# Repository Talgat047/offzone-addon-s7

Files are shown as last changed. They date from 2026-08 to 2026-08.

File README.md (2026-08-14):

# S7 Badge for OFFZONE 2024

## Authors
- leitosama
- Unknown actor #2
- Unknown actor #3

## Design idea
- S7 Airplane with Siberian forest livery
- Airplane has air navigation lights like real planes

## Схема

`project/offzone-addon-s7.kicad_sch` — схема аэронавигационных огней, собранная по
референсному скриншоту из симулятора. До этого файл был пустой заготовкой: плата
содержала только контур и шелкографию, без футпринтов и цепей.

### Как это работает

```mermaid
flowchart LR
    VCC(["+3V"])
    GND(["GND"])

    VCC --> R1["R1 200k"] --> DIS(["DIS"])
    DIS --> R2["R2 100k"] --> TC(["TC"])
    TC --> C1["C1 10µF"] --> GND

    DIS -.->|dis| U1
    TC  -.->|tr, th| U1
    VCC -.->|Vcc, rst| U1
    U1["U1 LMC555"] -->|out| R3["R3 1k"] -->|база| Q1["Q1 КТ3153А9"]
    U1 --> GND

    VCC --> R4["R4 100"] --> BLINK(["BLINK"])
    BLINK -->|коллектор| Q1 --> GND

    BLINK --> D1["D1 мигает"] --> GND
    BLINK --> D2["D2 мигает"] --> GND
    BLINK --> D3["D3 мигает"] --> GND

    VCC --> R5["R5 100"] --> D4["D4 постоянно"] --> GND
    VCC --> R6["R6 100"] --> D5["D5 постоянно"] --> GND
```

Узел `BLINK` — это коллектор Q1. Пока `out` = 0, Q1 закрыт, R4 подтягивает `BLINK`
вверх и D1..D3 светятся. Когда `out` = 1, Q1 открывается и шунтирует `BLINK` на землю —
мигающие огни гаснут. D4 и D5 запитаны от +3V напрямую через R5/R6 и горят постоянно.

### Тайминги

| Параметр | Формула | Значение |
|---|---|---|
| `out` = 1 (огни погашены) | 0,693 · (R1 + R2) · C1 | 2,08 с |
| `out` = 0 (вспышка) | 0,693 · R2 · C1 | 0,69 с |
| Период | сумма | 2,77 с (≈ 0,36 Гц) |
| Скважность | — | 75 % |

Получается вспышка 0,69 с примерно каждые 2,8 с, то есть около 22 вспышек в минуту.

### Цепи

| Цепь | Выводы |
|---|---|
| `+3V0` | R1.1, R4.1, R5.1, R6.1, U1.4 (`/RESET`), U1.8 (`VCC`) |
| `GND` | C1.2, D1.1, D2.1, D3.1, D4.1, D5.1, Q1.3 (Э), U1.1 (`GND`) |
| `DIS` | R1.2, R2.1, U1.7 (`DIS`) |
| `TC` | C1.1, R2.2, U1.2 (`/TR`), U1.6 (`THR`) |
| `BLINK` | Q1.1 (К), R4.2, D1.2, D2.2, D3.2 |
| — | U1.3 (`OUT`) → R3.1 |
| — | R3.2 → Q1.2 (Б) |
| — | R5.2 → D4.2, R6.2 → D5.2 |
| — | U1.5 (`CONT`) — не подключён (no-connect) |

### BOM

| Поз. | Номинал | Корпус | LCSC | Примечание |
|---|---|---|---|---|
| U1 | LMC555M/TR | SOP-8 | C356725 | **CMOS**-таймер, см. замечание ниже |
| R1 | 200 кОм | 0603 | C25811 | задающая цепь |
| R2 | 100 кОм | 0603 | C25803 | задающая цепь |
| C1 | 10 мкФ | 0805 | C1713 | задающая цепь |
| R3 | 1 кОм | 0603 | C21190 | база Q1 |
| Q1 | КТ3153А9 | КТ-46А (SOT-23) | ChipDip | n-p-n, цоколёвка **1-К, 2-Б, 3-Э** |
| R4 | 100 Ом | 0603 | C105588 | общий токозадающий для D1..D3 |
| R5, R6 | 100 Ом | 0603 | C105588 | токозадающие для D4, D5 |
| D1..D3 | LED | 0805 | — | мигающие (строб / маяк) |
| D4, D5 | LED | 0805 | — | постоянные (БАНО) |

Конкретные светодиоды не выбраны: цвета — на ваше усмотрение. По-самолётному это
красный на левом крыле, зелёный на правом и белые стробы. В файле EasyEDA у D1..D5
подставлен корпус `LED0805`, партномер нужно назначить.

### Тот же проект для EasyEDA

`project/offzone-addon-s7-easyeda.json` — та же схема в формате EasyEDA Standard.
Открывается через **File → Open → EasyEDA**. Графика символов взята из библиотеки
LCSC и целиком встроена в файл, а партномера едут в атрибуте `BOM_Supplier Part`,
так что схему можно вести в плату.

`project/offzone-addon-s7-easyeda-sheet.json` — тот же лист без обёртки проекта
(один документ `docType: 1`). Запасной вариант, если проектный файл не открывается.

Отличия от KiCad-версии только в оформлении: цепи `+3V`, `GND`, `TC`, `DIS`, `OUT`,
`BLINK` разведены сетевыми метками, поэтому длинных перемычек вокруг корпуса U1 нет.
Список цепей совпадает с таблицей выше цепь в цепь.

> **Почему в компонентах пустые uuid.** Сначала в заголовки `LIB` были подставлены
> `uuid`/`puuid` библиотечных документов LCSC. При импорте EasyEDA пытается привязать
> эти документы к вашей учётной записи, они ей не принадлежат — и импорт падает с
> `Permissions Error`, создавая пустой лист. Поля оставлены пустыми, как в системной
> рамке листа; на геометрию и BOM это не влияет.

### Замечания к схеме со скриншота

1. **Таймер должен быть CMOS.** Биполярный NE555 требует минимум 4,5 В и от 3 В не
   заработает. Поставлен LMC555 (питание от 1,5 В); равноценны TLC555 и ICM7555.
   В симуляторе таймер идеальный, поэтому там это не проявляется.
2. **Потребление великовато для CR2032.** D4 и D5 берут по ~11 мА постоянно, а R4 при
   открытом Q1 сжигает ~29 мА вхолостую — в среднем около 46 мА. CR2032 (~220 мАч)
   такой ток не держит. Если питание автономное, стоит поднять R5/R6 до 1–2 кОм и
   перенести D1..D3 в коллекторную цепь Q1 (тогда R4 работает только во время вспышки).
3. **Вывод `ctl` оставлен свободным**, как на скриншоте. На реальной плате его обычно
   шунтируют конденсатором 10 нФ на землю.
4. **У КТ3153А9 своя цоколёвка.** По даташитам «Далекс» и ОАО «Интеграл» в корпусе
   КТ-46А (SOT-23) вывод 1 — коллектор, 2 — база, 3 — эмиттер. У западных SOT-23
   (MMBT3904, BC847) порядок другой: 1 — база, 2 — эмиттер, 3 — коллектор. Посадочное
   место нужно нумеровать по даташиту, иначе транзистор включится «наизнанку».
   По параметрам запас большой: Iк max 400 мА против рабочих ~30 мА, h21э 100…300 —
   базового тока (3 В − 0,85 В)/1 кОм ≈ 2 мА хватает для насыщения с большим запасом.

### Что осталось сделать

- Футпринты компонентам не назначены — цепи в `.kicad_pcb` ещё не разведены.
- Источник питания в схеме не нарисован: +3V приходит либо с хост-бейджа через разъём
  аддона, либо от CR2032. Разъём/держатель нужно добавить отдельно.

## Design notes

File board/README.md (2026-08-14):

# Плата-самолёт: разводка

`plane_easyeda_routed.json` — плата 65 × 65,5 мм в формате EasyEDA Standard,
собранная из расстановки в `plane_easyeda.json` и разведённая полностью.
Открывается через **File → Open → EasyEDA**.

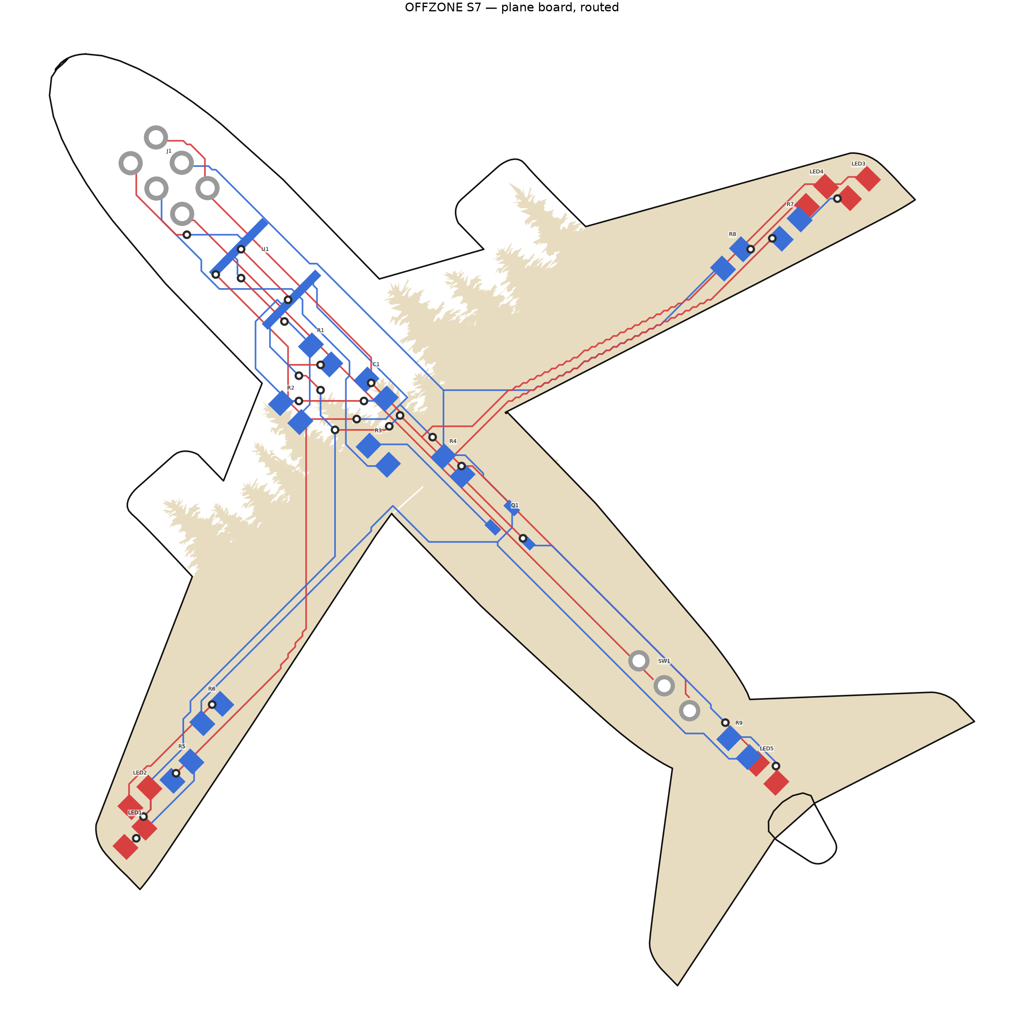
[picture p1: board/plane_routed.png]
разводка


## Что изменено относительно исходной расстановки

| Что | Было | Стало | Почему |
|---|---|---|---|
| Q1 | `KT-13-SMD`, три площадки в ряд с шагом 2,5 мм, цепи 1-GND 2-LEDDRV 3-BASE | `SOT-23`, цепи **1-LEDDRV (К), 2-BASE (Б), 3-GND (Э)** | КТ3153А9 выпускается в КТ-46А (SOT-23), и его цоколёвка — 1 коллектор, 2 база, 3 эмиттер |
| LED1, LED3 | питались от `LEDDRV` | питаются от `VCC` через R5 и R7 | по схеме со скриншота два огня горят постоянно |
| LED2 | — | сдвинут на 0,41 мм от LED1 | площадки LED1.2(GND) и LED2.1(A2) стояли в 0,068 мм |
| LED4 | — | сдвинут на 0,56 мм от LED3 | площадки LED3.1(A3) и LED4.2(GND) стояли в 0,004 мм |

Два последних пункта — исправление замыкания: в исходной расстановке пары на
законцовках стояли в 2,42 мм друг от друга, и встречные площадки корпусов 0805
соприкасались. LED2 и LED3 оказались бы закорочены на землю и не зажглись бы.
Теперь зазор 0,315 и 0,316 мм.

## Огни

| Позиция | Место | Режим |
|---|---|---|
| LED1 | законцовка левого крыла | постоянно (БАНО) |
| LED2 | законцовка левого крыла | мигает |
| LED3 | законцовка правого крыла | постоянно (БАНО) |
| LED4 | законцовка правого крыла | мигает |
| LED5 | хвост | мигает |

Разбивка «по одному постоянному на крыло, остальные мигают» повторяет
аэронавигационные огни настоящего самолёта: ровные БАНО на крыльях плюс
проблесковые маяки. Цвета светодиодов не заданы — по-самолётному это красный
на левом крыле и зелёный на правом.

## Параметры разводки

| Параметр | Значение |
|---|---|
| Слои | 2 (TopLayer — светодиоды, BottomLayer — обвязка) |
| Ширина дорожки | 0,254 мм (10 mil) |
| Зазор | 0,254 мм (10 mil) |
| Переходное отверстие | 0,61 мм, сверло 0,3 мм |
| Отступ меди от контура | 0,5 мм |
| Дорожек / переходов | 50 / 28 |
| Суммарная длина дорожек | 532 мм |

Нормы с большим запасом относительно JLCPCB (минимум 0,127 мм / 5 mil).

## Проверки

`build_board.py` пересобирает плату из исходной расстановки и сам себя проверяет:

- каждая цепь — один связный остров меди (выводные площадки J1 и SW1 считаются
  соединяющими слои, как и переходные отверстия);
- нет нарушений зазора между дорожками и чужой медью;
- нет площадок разных цепей ближе 0,3 мм;
- ни одна дорожка, переход или площадка не выходит за контур платы и не попадает
  в отверстие под шнурок (проверено по 5926 точкам).

```
python build_board.py plane_easyeda.json plane_easyeda_routed.json
python render_pcb.py  plane_easyeda_routed.json plane_routed.png
```

## Чего в плате нет

- **Держателя батарейки.** По расчёту в `layout.py` при ширине 65 мм наибольшая
  вписанная окружность — 16,5 мм, а держателю CR2032 нужно 20 мм. Питание идёт
  через J1 (`VBAT`) и выключатель SW1.
- **Полигона земли.** Земля разведена дорожками; при желании можно залить
  полигон, но на таких токах это не обязательно.
- **Проверки зеркальности посадочных мест.** Компоненты стоят на нижнем слое, а
  генератор кладёт площадки без зеркалирования. Для двухвыводных резисторов и
  конденсаторов это неважно, но у U1 (SOIC-8), J1, SW1 и Q1 порядок выводов при
  монтаже снизу зеркалится. Это надо проверить до заказа — я эту логику не
  трогал, чтобы не расходиться с вашим генератором.

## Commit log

2026-08-14 Add navigation lights schematic
    offzone-addon-s7.kicad_sch was an empty stub: the board carried only the
    outline and silkscreen, with no footprints and no nets. Fill it in with the
    circuit from the reference simulator screenshot.
    - U1 CMOS 555 astable, R1 200k / R2 100k / C1 10uF -> 0.69 s flash every
    2.77 s (~0.36 Hz, 75% duty)
    - out -> R3 1k -> Q1 NPN low-side switch
    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
    [offzone-addon-s7.kicad_sch]
2026-08-14 Add EasyEDA version of the schematic
    project/offzone-addon-s7-easyeda.json holds the same circuit as the KiCad
    sheet, in EasyEDA Standard format (File -> Open -> EasyEDA). Symbols are the
    real LCSC ones, so footprints and part numbers come along and the sheet can be
    pushed straight to a board.
    Nets +3V, GND, TC, DIS, OUT and BLINK are joined by net labels rather than long
    wires, which keeps the routing around U1 free of crossings. The netlist is
    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
    [offzone-addon-s7.kicad_sch]
2026-08-14 Fix Permissions Error when importing the EasyEDA project
    The LIB headers carried the uuid/puuid of the LCSC library documents the
    symbols were pulled from. On import EasyEDA tries to attach those documents to
    the importing account; they belong to LCSC, so the call is rejected and the
    sheet lands empty behind a "Permissions Error" dialog.
    Leave those slots empty, the way the system sheet frame does. The symbol
    geometry is fully embedded in the sub-shapes, and the LCSC part number still
    travels in the BOM_Supplier Part attribute, so nothing is lost.
    Also match the document head to the project file that already opens for this
    account (editorVersion 6.5.51, same field set) and drop attributes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
2026-08-14 Switch Q1 to KT3153A9 and fix its pin order
    The part is KT3153A9 (Dalex / Integral), n-p-n in a KT-46A (SOT-23) package.
    Both datasheets agree its pin order is 1 = collector, 2 = base, 3 = emitter,
    which is NOT the western SOT-23 order the MMBT3904 symbol used (1 = base,
    2 = emitter, 3 = collector). Renaming alone would have wired the transistor
    inside out, so the symbol pins are renumbered to match the datasheet.
    KiCad now uses Device:Q_NPN_CBE; the EasyEDA sheet renumbers the borrowed
    symbol and drops the LCSC part attributes, since this part is sourced locally.
    Headroom is ample: 400 mA rating against ~30 mA of load, and h21e 100..300 with
    about 2 mA of base current keeps it well into s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
    [offzone-addon-s7.kicad_sch]
2026-08-14 Update net table and diagram for the new pin order
2026-08-14 Add the routed plane board
    board/plane_easyeda_routed.json is the 65 x 65.5 mm plane board taken from the
    existing placement and routed end to end: 50 tracks, 28 vias, 532 mm of copper
    on two layers at 10 mil track and 10 mil clearance.
    Three changes to the circuit on the way in:
    - Q1 becomes a SOT-23 for the KT3153A9, whose pin order is 1 collector,
    2 base, 3 emitter. The old KT-13 land had three pads in a row on 2.5 mm
    centres wired 1-GND 2-LEDDRV 3-BASE, which does not fit that part.
    - LED1 and LED3, one per wingtip, move from LEDDRV to VCC so they burn steady
    while LED2, LED4 and LED5 keep blinking, matching the reference circuit.
    - LED2 and LED4 shift 0.41 and 0.56 mm outward. B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
